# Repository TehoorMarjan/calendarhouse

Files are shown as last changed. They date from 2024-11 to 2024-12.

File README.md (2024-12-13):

# DIY Smart Advent Calendar House 🎄

> [!WARNING]  
> This project is a work in progress. While it can serve as inspiration, it is not ready for plug-and-play use and requires additional development and customization.

<div align="center">
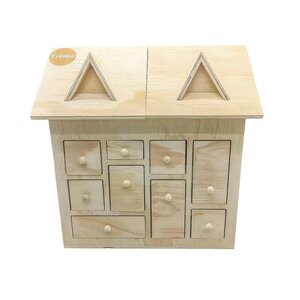
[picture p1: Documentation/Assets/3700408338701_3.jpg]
  
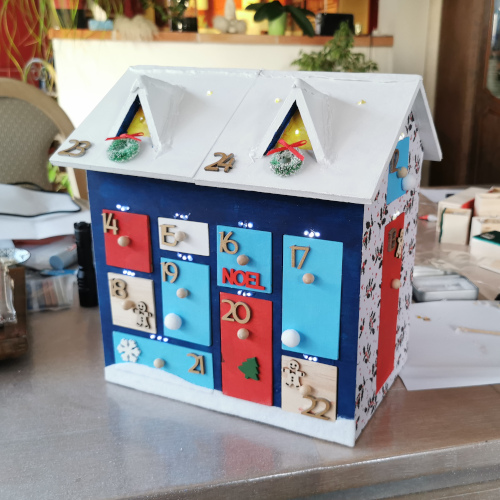
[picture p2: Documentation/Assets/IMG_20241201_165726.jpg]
  
</div>

A fun, interactive advent calendar looking like a miniature wooden house with a drawer for each day leading up to Christmas. This project combines craftsmanship with electronics to create a delightful experience for children and grown-ups!

## Project Highlights

- **Interactive LEDs**: Each day, a specific LED lights up to guide the child to the correct drawer.
- **Drawer Detection**: Detects when a drawer is opened using Hall-effect sensors and magnets.
- **Audio Playback**: Plays music, stories, or sounds depending on opened drawer, also giving feedback when wrong drawer is opened.
- **Light Show**: Features decorative light displays synchronized with sound playback. (🚧 Planned feature)

---

## Folder Structure

- **`Fritzing`**: Contains the initial schematics created with the Fritzing software.
- **`KiCAD`**: Detailed electronic schematics and PCB designs created with KiCAD.
- **`Firmware`**: A PlatformIO project featuring the ESP32 firmware (work in progress).
- **`Documentation`**: Includes relevant datasheets and schema exports.
- **`Design`**: Includes decoration ideas, paint tests, and images of the house design.

---

## Hardware Overview

### Electronics Used
1. **ESP32-WROOM**: The main microcontroller also used for USB 5V power supply.
2. **TLC5947 Module**: 24-channel PWM driver for controlling the LEDs above each drawer, From Adafruit.
3. **2x PCF8575 IO Expanders**: To read the state of the 24 drawers via Hall-effect sensors (12 IOs each, each expander can handle up to 16 IOs).
4. **MAX98357 I2C Amplifier**: For better audio output compared to the PAM8403 module. (🚧 Realised on-board, schematics to change yet.)
5. **SPI SD Card Reader**: To store music, sound effects, or stories. Could also host update files (OTA), parameters, ...
6. **Hall-effect Sensors (A3144)**: Each drawer gets a small 10x10x1 mm *neodymium* magnet *(ferrite would be too weak)* and Hall-effect sensor to detect openings. `A3144` was selected, but requires improvement due to its active-low nature ("magnet present = on" ⇒ current is drawn almost all the time). Should select a non-latching active-high sensor instead.

---

## Tools Used

- **Fritzing**: Initial circuit layout and basic design.
- **KiCAD**: Advanced schematics and PCB design for production-ready boards.
- **PlatformIO**: Development environment for writing Arduino-based firmware for the ESP32.

---

## Getting Started

### Prerequisites
- Install [PlatformIO](https://platformio.org/) to compile and upload firmware.
- Required dependencies for the ESP32 firmware can be installed using:
  ```bash
  pio pkg install
  ```

### Hardware Assembly
1. **Electronics Integration**:
   - Connect ESP32, LEDs, sensors, and audio modules as per the schematics in the `KiCAD` folder.
   - Solder the components onto the PCB designed in `KiCAD` or use a breadboard for prototyping.

2. **House Assembly**:
   - Paint and decorate the wooden house using ideas from the `Design` folder.
   - Attach the LEDs above each drawer and install Hall-effect sensors inside.

3. **Calibration**:
   - Test the sensor detection and calibrate the thresholds for drawer opening/closing.
   - Load the firmware onto the ESP32 to test the LED control and audio playback.

## Future Enhancements

- Add Wi-Fi capabilities for remote control (🚧 ongoing).
- Integrate a mobile/web app.
- Explore active-high Hall-effect sensors for smoother drawer state detection.

## License

Feel free to reuse components of this project, **subject to their respective licenses**. Please note that third-party components (such as Fritzing and KiCAD parts) may have their own licensing terms, which you should review accordingly. (⚠️ TODO: Check the licenses for each part).

### My Original Work:

Released under [CC0 1.0 Universal (Public Domain Dedication)](https://creativecommons.org/publicdomain/zero/1.0/). This means you can use *my* artwork and *my* code for any purpose without any restrictions.

In short, you are free to use, modify, and distribute both the code and artwork with very few limitations.

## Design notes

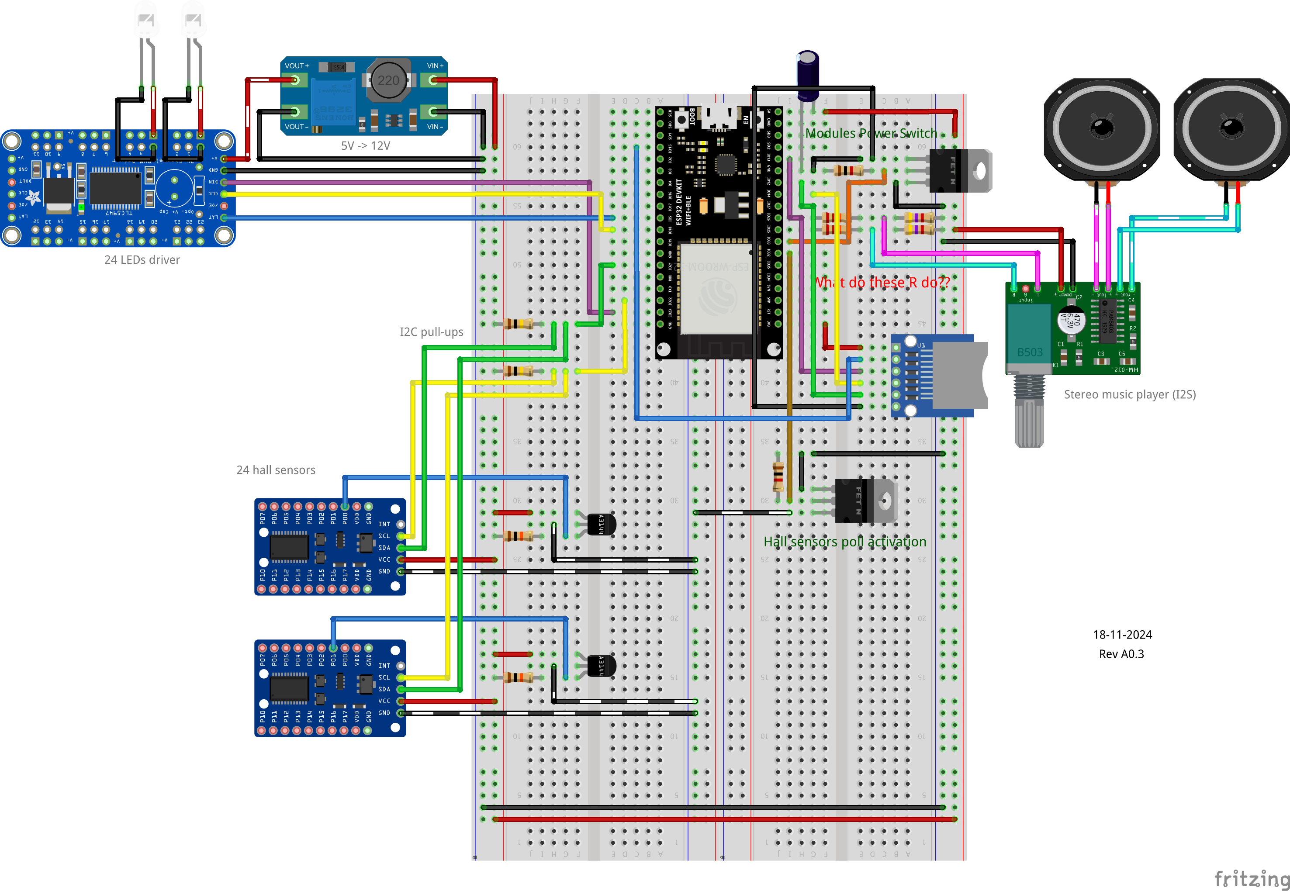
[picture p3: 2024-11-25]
Documentation/Exports/CalendarHouse_bb.png

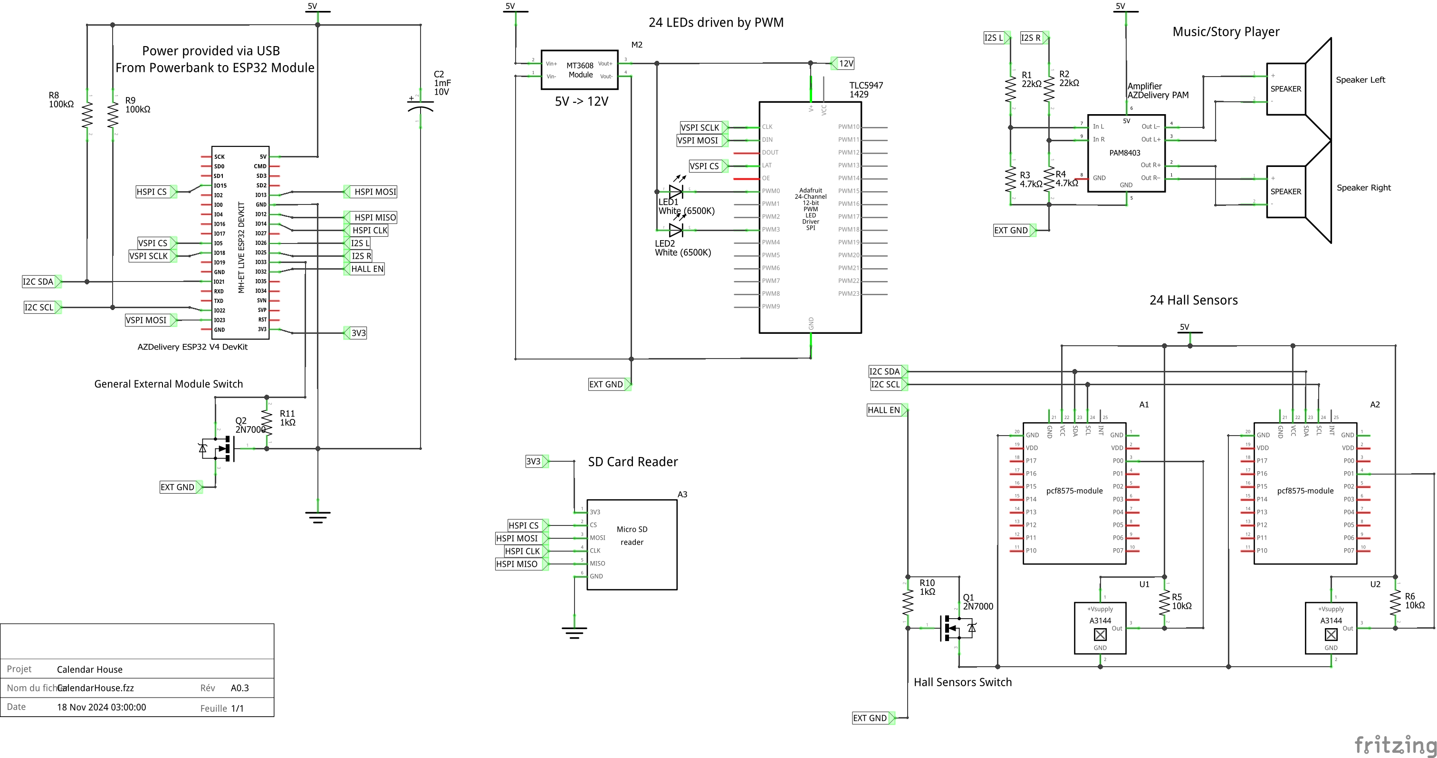
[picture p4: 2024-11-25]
Documentation/Exports/CalendarHouse_sch.png

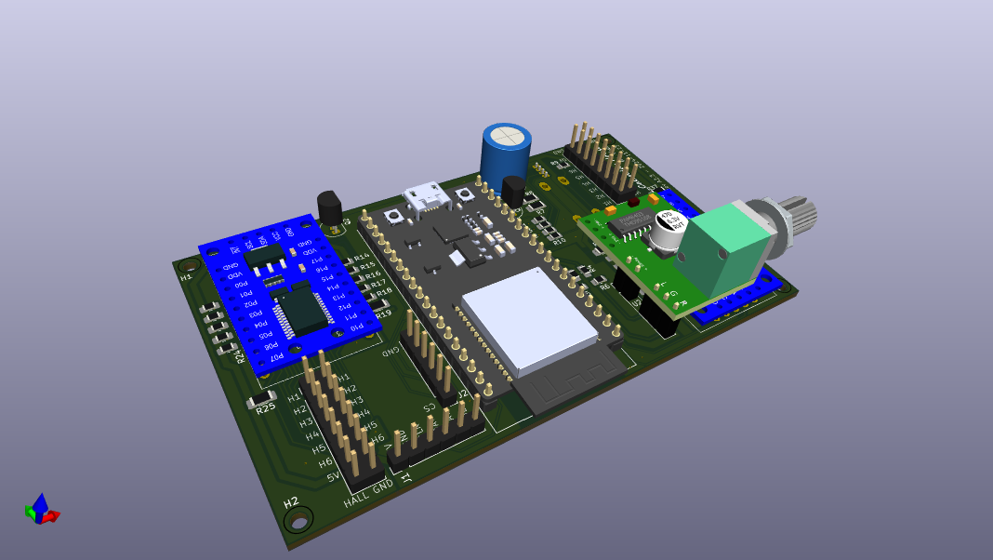
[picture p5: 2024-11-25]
Documentation/Exports/CalendarHouse3D.png

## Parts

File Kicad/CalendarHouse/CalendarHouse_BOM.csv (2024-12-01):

Reference | Value | Datasheet | Footprint | Qty | DNP | Availability
C1 | 1m | ~ | Capacitor_THT:C_Radial_D10.0mm_H12.5mm_P5.00mm | 1 |  | In Stock
R13 | 68 | ~ | Resistor_SMD:R_0805_2012Metric_Pad1.20x1.40mm_HandSolder | 1 |  | Ordered
R7,R8 | 100 | ~ | Resistor_SMD:R_1206_3216Metric_Pad1.30x1.75mm_HandSolder | 2 |  | Ordered
R11 | 100 | ~ | Resistor_SMD:R_0805_2012Metric_Pad1.20x1.40mm_HandSolder | 1 |  | Ordered
R12 | 220 | ~ | Resistor_SMD:R_0805_2012Metric_Pad1.20x1.40mm_HandSolder | 1 |  | Ordered
R1,R2,R9 | 2.2K | ~ | Resistor_SMD:R_0805_2012Metric_Pad1.20x1.40mm_HandSolder | 3 |  | Ordered
R5,R6,R10 | 4.7K | ~ | Resistor_SMD:R_0805_2012Metric_Pad1.20x1.40mm_HandSolder | 3 |  | Ordered
R14,R15,R16,R17,R18,R20,R21,R22,R23,R24,R26,R27,R28,R29,R30,R32,R33,R34,R35,R36 | 10K | ~ | Resistor_SMD:R_0805_2012Metric_Pad1.20x1.40mm_HandSolder | 20 |  | Ordered
R19,R25,R31,R37 | 10K | ~ | Resistor_SMD:R_1206_3216Metric_Pad1.30x1.75mm_HandSolder | 4 |  | Ordered
R3,R4 | 22K | ~ | Resistor_SMD:R_0805_2012Metric_Pad1.20x1.40mm_HandSolder | 2 |  | Ordered
Q1,Q2 | 2N7000 | https://www.vishay.com/docs/70226/70226.pdf | Package_TO_SOT_THT:TO-92_Inline | 2 |  | In Stock
U2 | AZPAM8403 | https://cdn.shopify.com/s/files/1/1509/1638/files/Mini-PAM8403_datasheet.pdf?v=1646835767 | Kicad:Mini PAM8403 Module OnlyInput | 1 |  | In Stock
J3,J4 | Conn_02x08_Odd_Even | ~ | Connector_PinHeader_2.54mm:PinHeader_2x08_P2.54mm_Vertical | 2 |  | Ordered
J1 | Conn_1x6_LED_MOD | ~ | Connector_PinHeader_2.54mm:PinHeader_1x06_P2.54mm_Vertical | 1 |  | Ordered
J2 | Conn_1x6_SD_CARD | ~ | Connector_PinHeader_2.54mm:PinHeader_1x06_P2.54mm_Vertical | 1 |  | Ordered
U1 | DEVKIT_V1_ESP32-WROOM-32 | https://www.espressif.com/sites/default/files/documentation/esp32_datasheet_en.pdf | Kicad:MODULE_DEVKIT_V1_ESP32-WROOM-32 | 1 |  | In Stock
D1 | LED_RKBG | https://www.farnell.com/datasheets/3497864.pdf | LED_THT:LED_D5.0mm-4_RGB | 1 |  | In Stock
SW1 | SW_Push | https://sten-eswitch-13110800-production.s3.amazonaws.com/system/asset/product_line/data_sheet/143/TL1100.pdf | Button_Switch_THT:SW_PUSH-12mm | 1 |  | In Stock
U3,U4 | ZKEESHOP_PCF8575_MOD | https://www.tinytronics.nl/shop/index.php?route=product/product/get_file&file=3903/pcf8575.pdf | Kicad:16-bit IO Expander | 2 |  | In Stock

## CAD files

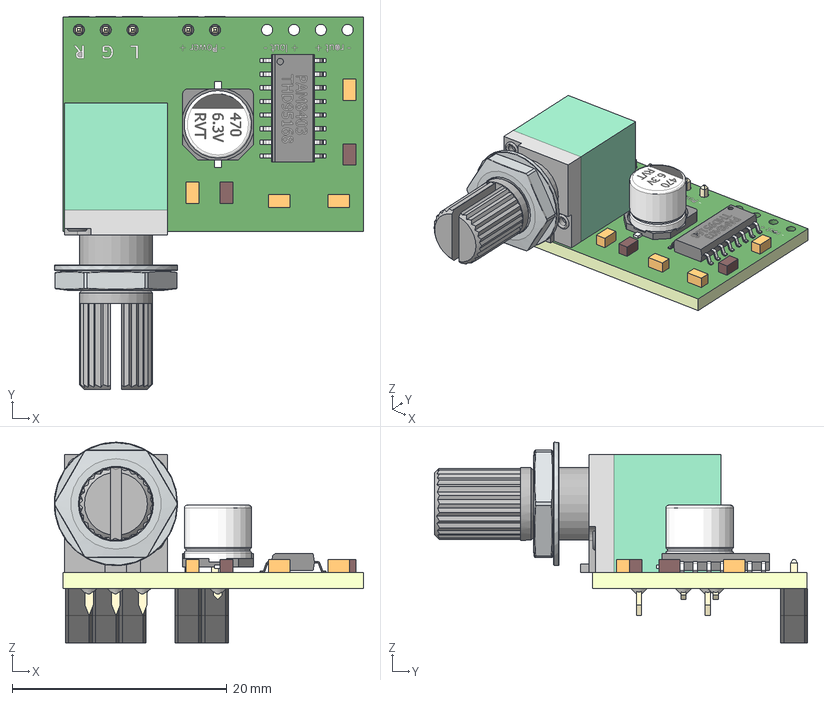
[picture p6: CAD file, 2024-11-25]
Kicad/Parts/PAM8403 5V 2 Channel USB Digital Audio with Potentionmeter Switch Modded.stp
28.8 x 34.7 x 18.7 mm
PAM8403 5V 2 Channel USB Digital Audio with Potentionmeter Switch009
PAM8403 5V 2 Channel USB Digital Audio with Potentionmeter Switch010
PAM8403 5V 2 Channel USB Digital Audio with Potentionmeter Switch011
PAM8403 5V 2 Channel USB Digital Audio with Potentionmeter Switch013 x 2
PAM8403 5V 2 Channel USB Digital Audio with Potentionmeter Switch014 x 2
PAM8403 5V 2 Channel USB Digital Audio with Potentionmeter Switch015
PAM8403 5V 2 Channel USB Digital Audio with Potentionmeter Switch016
PAM8403 5V 2 Channel USB Digital Audio with Potentionmeter Switch017
PAM8403 5V 2 Channel USB Digital Audio with Potentionmeter Switch022
PAM8403 5V 2 Channel USB Digital Audio with Potentionmeter Switch023
PAM8403 5V 2 Channel USB Digital Audio with Potentionmeter Switch033

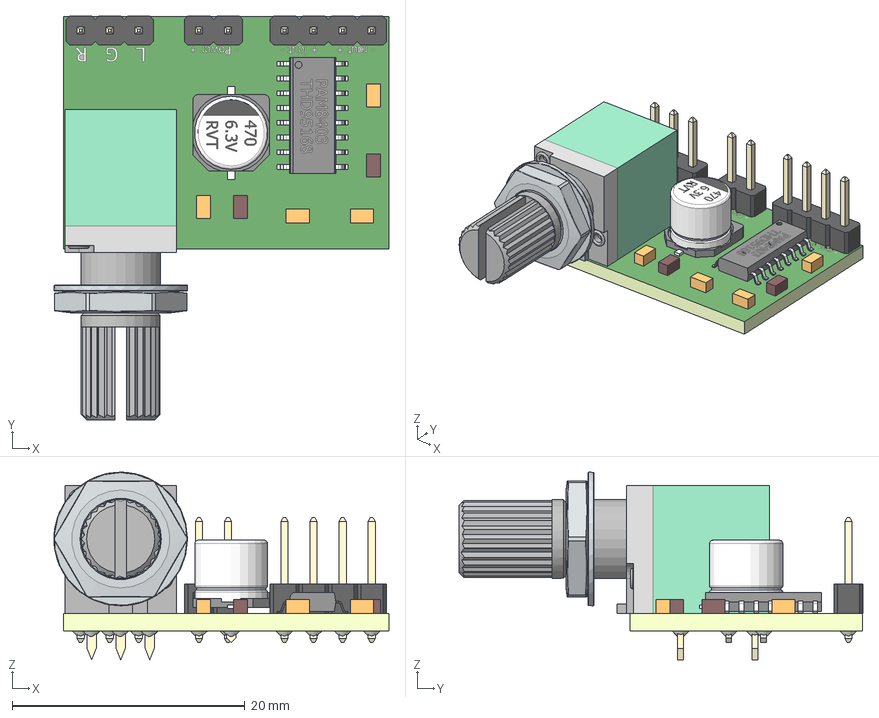
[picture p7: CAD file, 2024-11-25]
Kicad/Parts/PAM8403 5V 2 Channel USB Digital Audio with Potentionmeter Switch.stp
28.8 x 34.7 x 16.1 mm

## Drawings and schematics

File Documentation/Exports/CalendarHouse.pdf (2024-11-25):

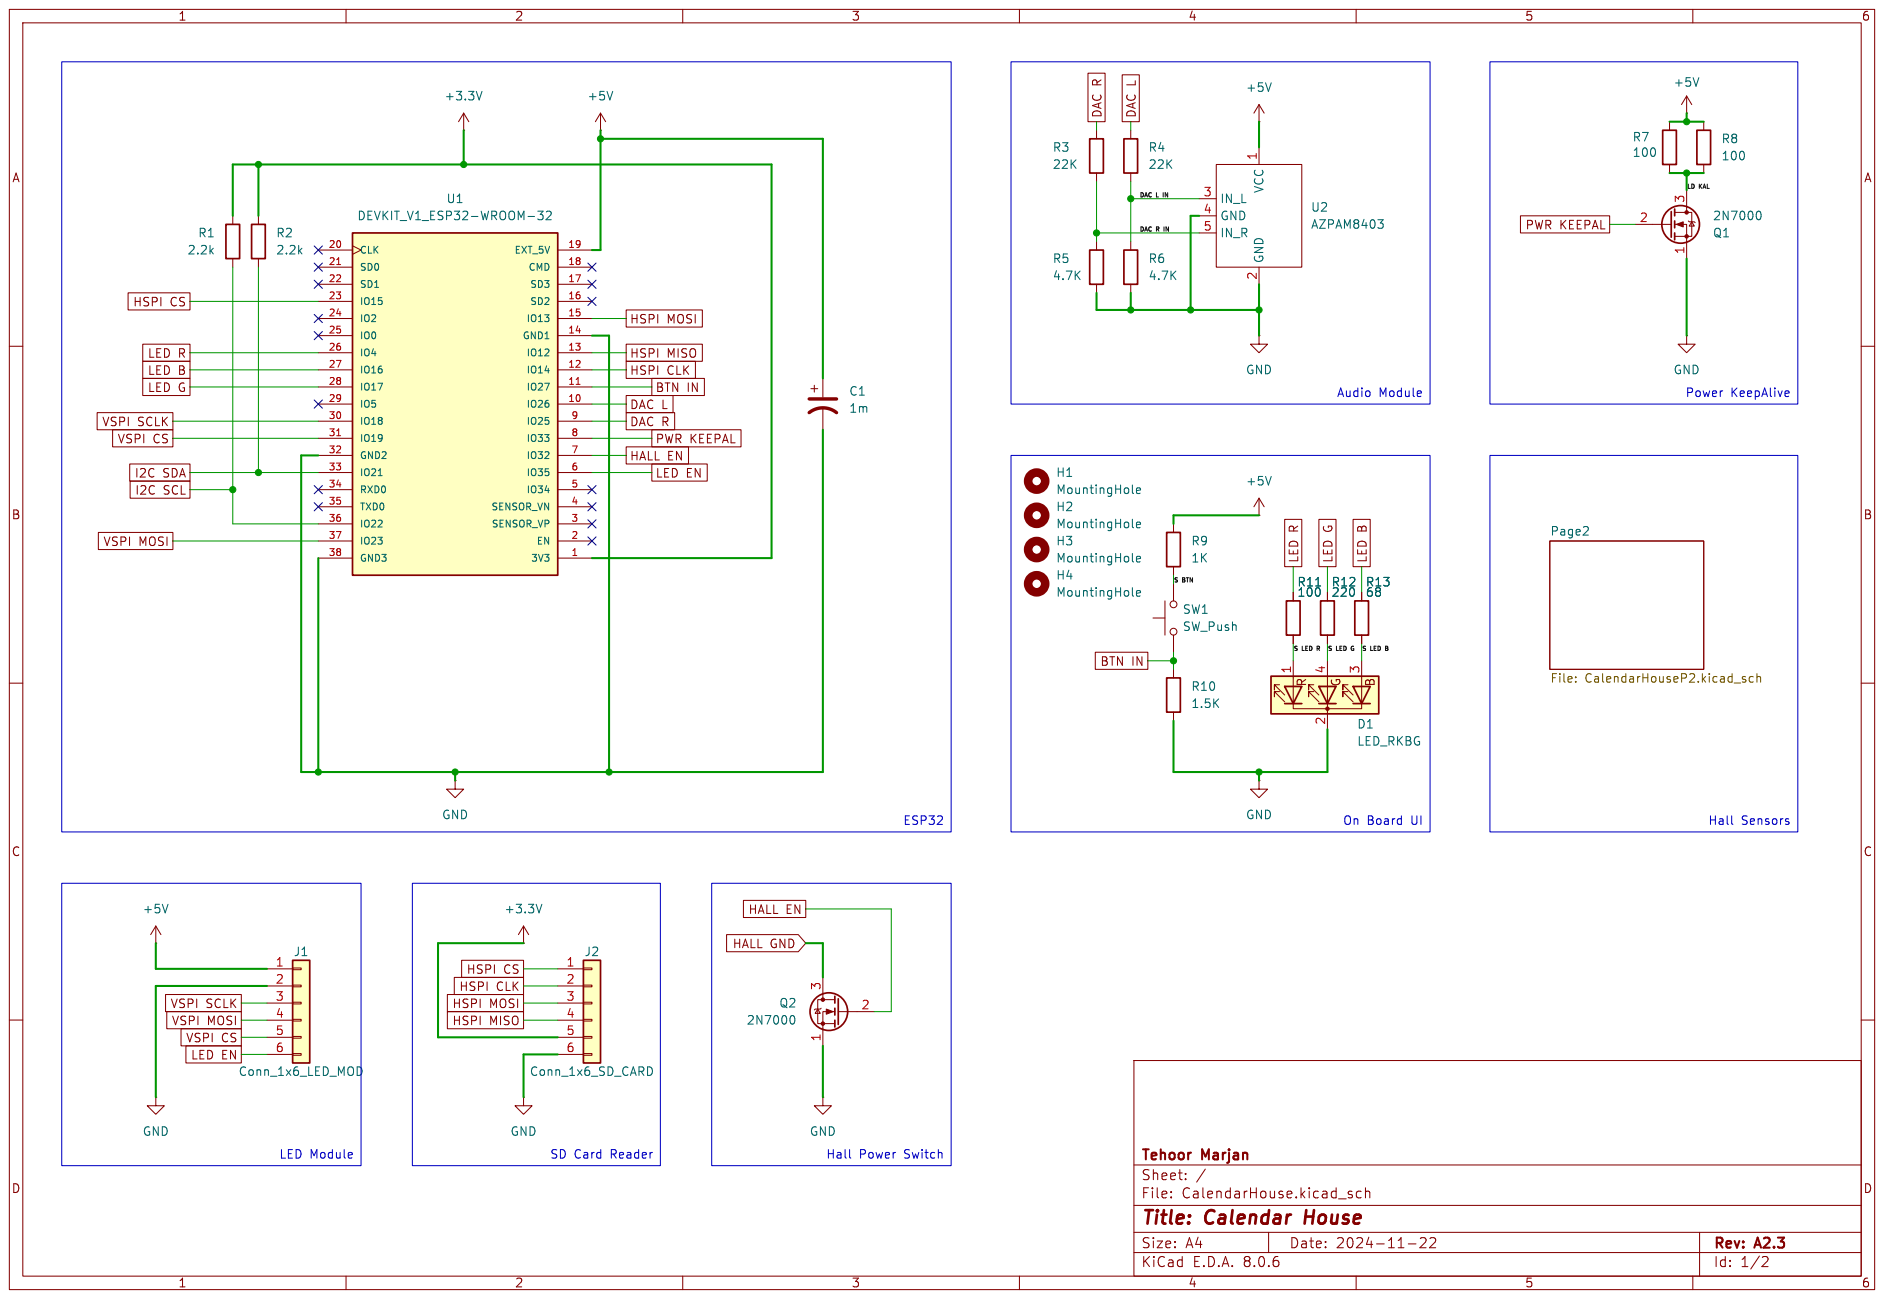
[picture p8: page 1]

LD KAL DAC L IN

PWR KEEPAL HSPI CLK HSPI MOSI
HSPI MOSI HALL EN

PWR KEEPAL HSPI MISO
HSPI CLK
BTN IN

VSPI MOSI VSPI SCLK

Id: 1/2 Title: Calendar House

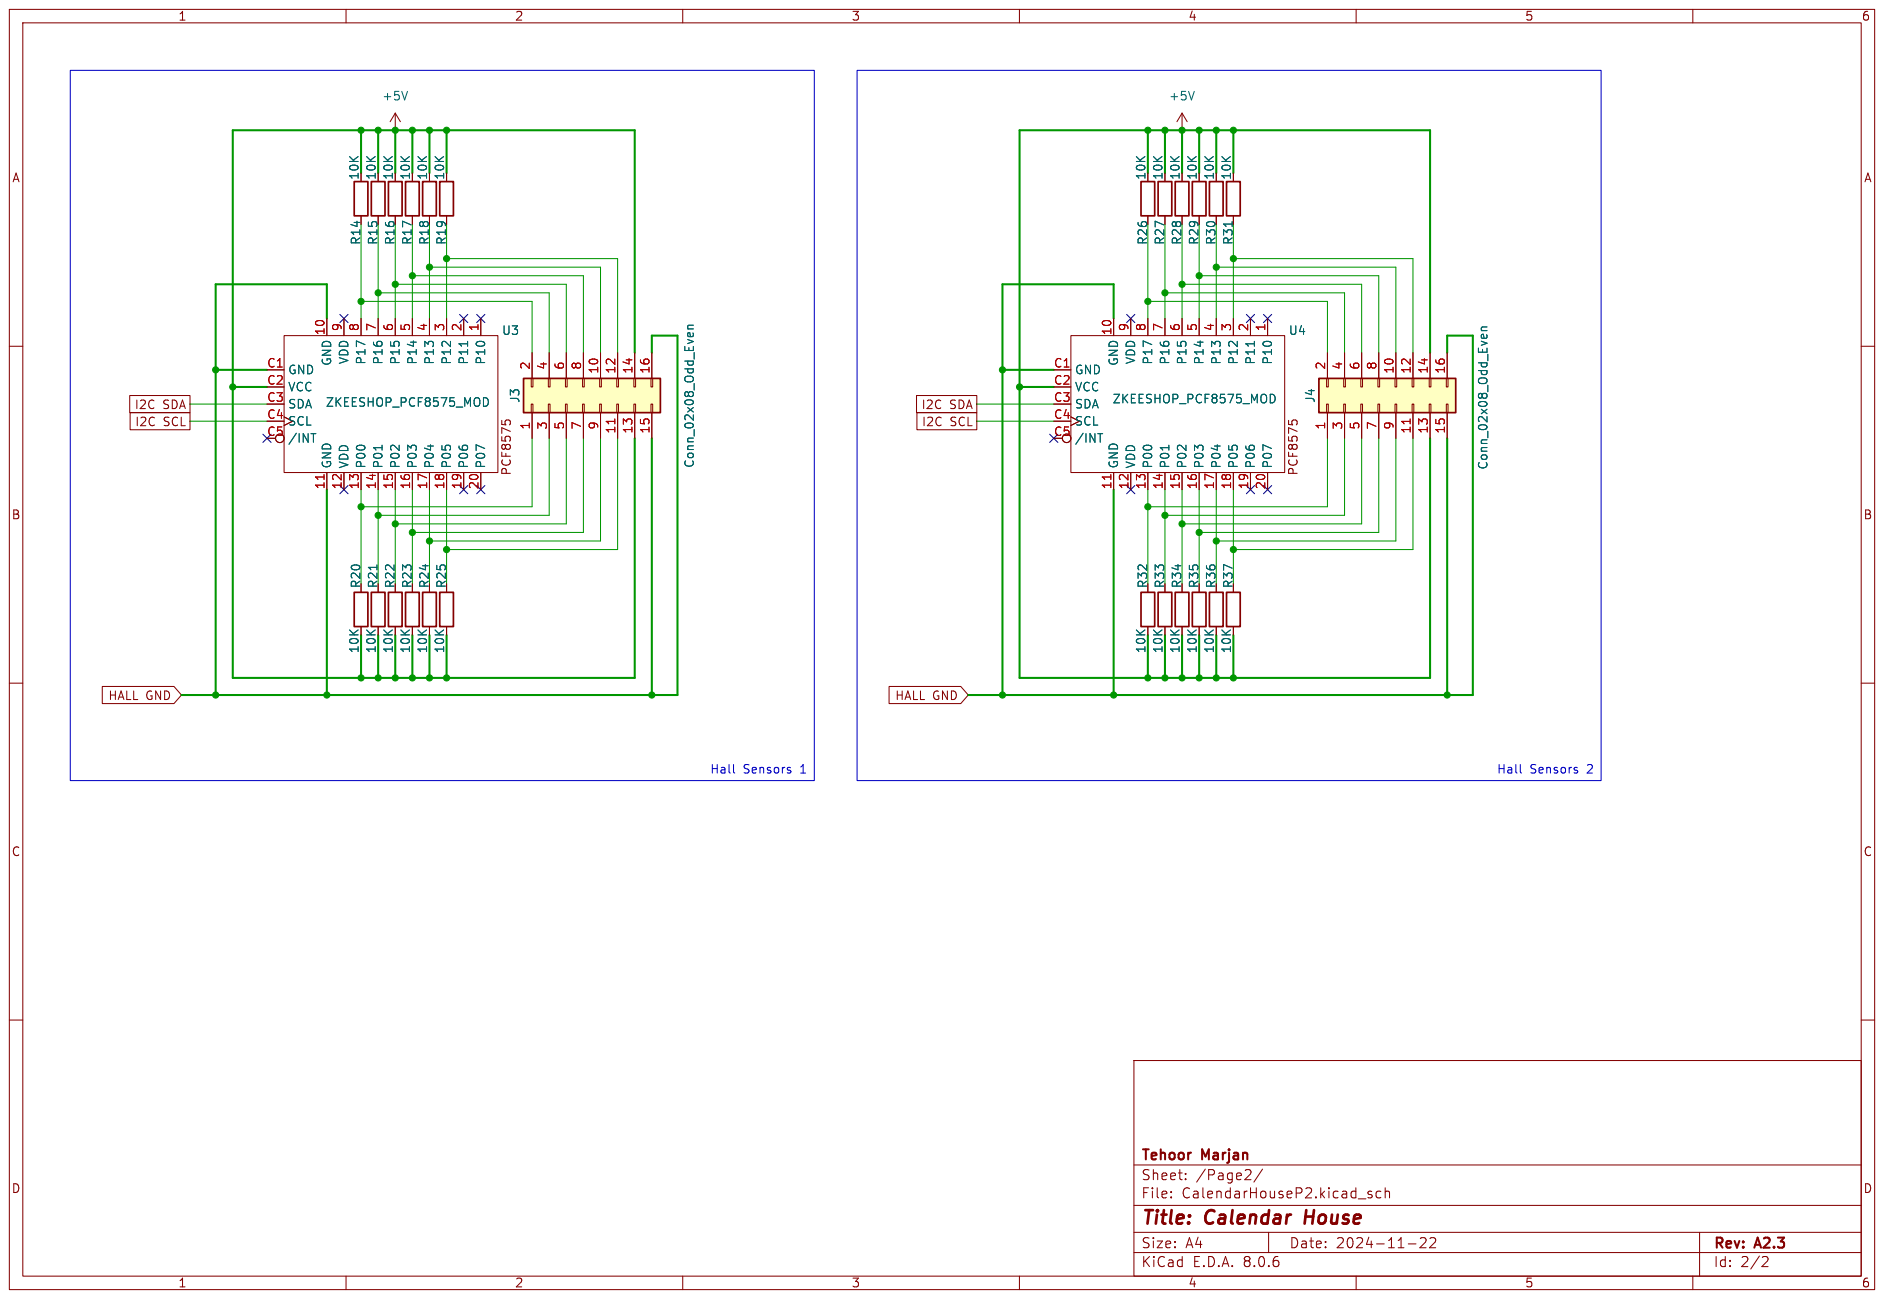
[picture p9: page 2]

9 GND C1 VCC C2 SDA C3 SCL C4

Id: 2/2 Title: Calendar House

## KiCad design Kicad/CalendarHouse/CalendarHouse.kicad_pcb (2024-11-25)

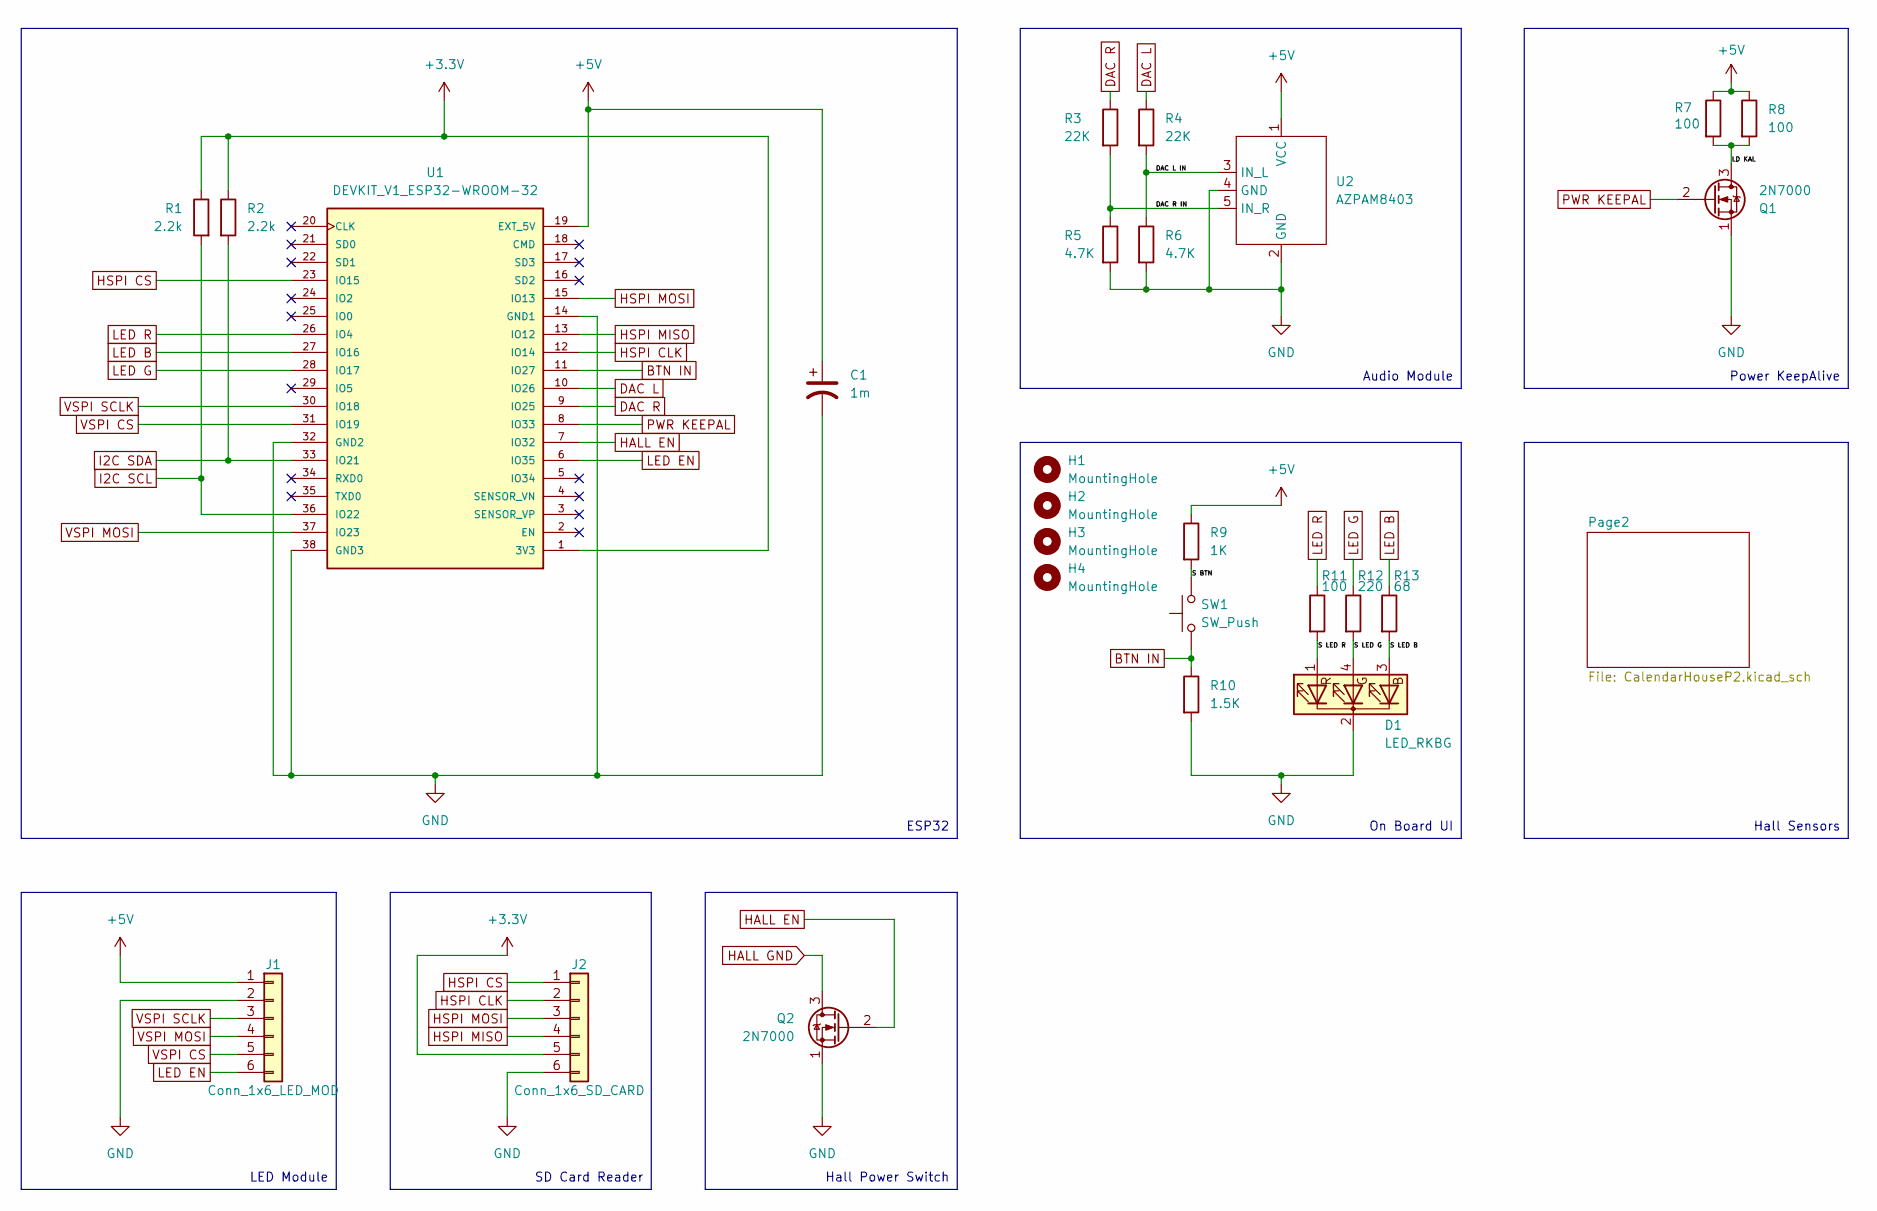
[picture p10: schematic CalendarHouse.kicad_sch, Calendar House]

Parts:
C1: 1m; C_Radial_D10.0mm_H12.5mm_P5.00mm
D1: LED_RKBG; LED_D5.0mm-4_RGB
H1, H2, H3, H4: MountingHole; MountingHole_2.2mm_M2_DIN965
J1: Conn_1x6_LED_MOD; PinHeader_1x06_P2.54mm_Vertical
J2: Conn_1x6_SD_CARD; PinHeader_1x06_P2.54mm_Vertical
Q1, Q2: 2N7000; TO-92_Inline
R1, R2: 2.2k; R_0805_2012Metric_Pad1.20x1.40mm_HandSolder
R3, R4: 22K; R_0805_2012Metric_Pad1.20x1.40mm_HandSolder
R5, R6: 4.7K; R_0805_2012Metric_Pad1.20x1.40mm_HandSolder
R7, R8: 100; R_1206_3216Metric_Pad1.30x1.75mm_HandSolder
R9: 1K; R_0805_2012Metric_Pad1.20x1.40mm_HandSolder
R10: 1.5K; R_0805_2012Metric_Pad1.20x1.40mm_HandSolder
R11: 100; R_0805_2012Metric_Pad1.20x1.40mm_HandSolder
R12: 220; R_0805_2012Metric_Pad1.20x1.40mm_HandSolder
R13: 68; R_0805_2012Metric_Pad1.20x1.40mm_HandSolder
SW1: SW_Push; SW_PUSH-12mm; MPN TL1100D
U1: DEVKIT_V1_ESP32-WROOM-32; MODULE_DEVKIT_V1_ESP32-WROOM-32; PARTREV N/A
U2: AZPAM8403; Mini PAM8403 Module OnlyInput

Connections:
+3.3V: J2.5, R1.1, R2.1, U1.1 (3V3)
+5V: C1.1, J1.1, R7.1, R8.1, R9.1, U1.19 (EXT_5V), U2.1 (VCC); also elsewhere on the board
/DAC L IN: R4.2, R6.1, U2.3 (IN_L)
/DAC R IN: R3.2, R5.1, U2.5 (IN_R)
/LD KAL: Q1.3 (D), R7.2, R8.2
/S BTN: R9.2, SW1.2
/S LED B: D1.3 (BA), R13.2
/S LED G: D1.4 (GA), R12.2
/S LED R: D1.1 (RA), R11.2
BTN IN: R10.1, SW1.1, U1.11 (IO27)
DAC L: R4.1, U1.10 (IO26)
DAC R: R3.1, U1.9 (IO25)
GND: C1.2, D1.2 (K), J1.2, J2.6, Q1.1 (S), Q2.1 (S), R5.2, R6.2, R10.2, U1.14 (GND1), U1.32 (GND2), U1.38 (GND3), U2.2 (GND), U2.4 (GND)
HALL EN: Q2.2 (G), U1.7 (IO32)
HALL GND: Q2.3 (D); also elsewhere on the board
HSPI CLK: J2.2, U1.12 (IO14)
HSPI CS: J2.1, U1.23 (IO15)
HSPI MISO: J2.4, U1.13 (IO12)
HSPI MOSI: J2.3, U1.15 (IO13)
I2C SCL: R1.2, U1.36 (IO22); also elsewhere on the board
I2C SDA: R2.2, U1.33 (IO21); also elsewhere on the board
LED B: R13.1, U1.27 (IO16)
LED EN: J1.6, U1.6 (IO35)
LED G: R12.1, U1.28 (IO17)
LED R: R11.1, U1.26 (IO4)
PWR KEEPAL: Q1.2 (G), U1.8 (IO33)
VSPI CS: J1.5, U1.31 (IO19)
VSPI MOSI: J1.4, U1.37 (IO23)
VSPI SCLK: J1.3, U1.30 (IO18)

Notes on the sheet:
Power KeepAlive
Audio Module
LED Module
ESP32
Hall Sensors
Hall Power Switch
On Board UI
SD Card Reader

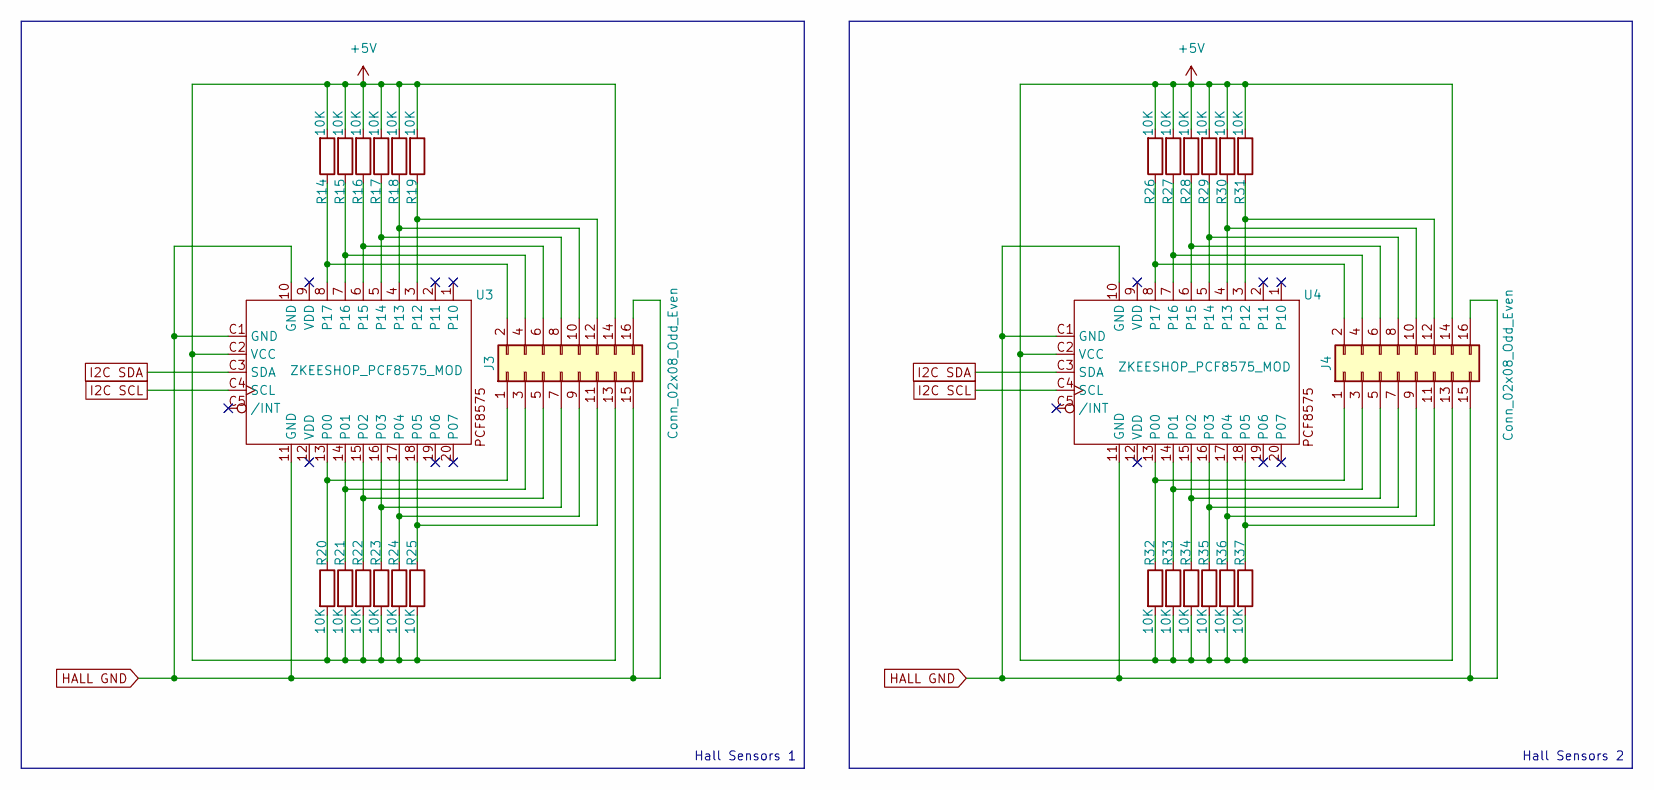
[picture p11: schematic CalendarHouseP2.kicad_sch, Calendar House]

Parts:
J3, J4: Conn_02x08_Odd_Even; PinHeader_2x08_P2.54mm_Vertical
R14, R15, R16, R17, R18, R20, R21, R22, R23, R24, R26, R27, R28, R29, R30, R32, R33, R34, R35, R36: 10K; R_0805_2012Metric_Pad1.20x1.40mm_HandSolder
R19, R25, R31, R37: 10K; R_1206_3216Metric_Pad1.30x1.75mm_HandSolder
U3, U4: ZKEESHOP_PCF8575_MOD; 16-bit IO Expander

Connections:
+5V: J3.13, J3.14, J4.13, J4.14, R14.2, R15.2, R16.2, R17.2, R18.2, R19.2, R20.2, R21.2, R22.2, R23.2, R24.2, R25.2, R26.2, R27.2, R28.2, R29.2, R30.2, R31.2, R32.2, R33.2, R34.2, R35.2, R36.2, R37.2, U3.C2 (VCC), U4.C2 (VCC); also elsewhere on the board
HALL GND: J3.15, J3.16, J4.15, J4.16, U3.10 (GND), U3.11 (GND), U3.C1 (GND), U4.10 (GND), U4.11 (GND), U4.C1 (GND); also elsewhere on the board
I2C SCL: U3.C4 (SCL), U4.C4 (SCL); also elsewhere on the board
I2C SDA: U3.C3 (SDA), U4.C3 (SDA); also elsewhere on the board
unnamed: J3.1, R20.1, U3.13 (P00)
unnamed: J3.2, R14.1, U3.8 (P17)
unnamed: J3.3, R21.1, U3.14 (P01)
unnamed: J3.4, R15.1, U3.7 (P16)
unnamed: J3.5, R22.1, U3.15 (P02)
unnamed: J3.6, R16.1, U3.6 (P15)
unnamed: J3.7, R23.1, U3.16 (P03)
unnamed: J3.8, R17.1, U3.5 (P14)
unnamed: J3.9, R24.1, U3.17 (P04)
unnamed: J3.10, R18.1, U3.4 (P13)
unnamed: J3.11, R25.1, U3.18 (P05)
unnamed: J3.12, R19.1, U3.3 (P12)
unnamed: J4.1, R32.1, U4.13 (P00)
unnamed: J4.2, R26.1, U4.8 (P17)
unnamed: J4.3, R33.1, U4.14 (P01)
unnamed: J4.4, R27.1, U4.7 (P16)
unnamed: J4.5, R34.1, U4.15 (P02)
unnamed: J4.6, R28.1, U4.6 (P15)
unnamed: J4.7, R35.1, U4.16 (P03)
unnamed: J4.8, R29.1, U4.5 (P14)
unnamed: J4.9, R36.1, U4.17 (P04)
unnamed: J4.10, R30.1, U4.4 (P13)
unnamed: J4.11, R37.1, U4.18 (P05)
unnamed: J4.12, R31.1, U4.3 (P12)

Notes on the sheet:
Hall Sensors 1
Hall Sensors 2

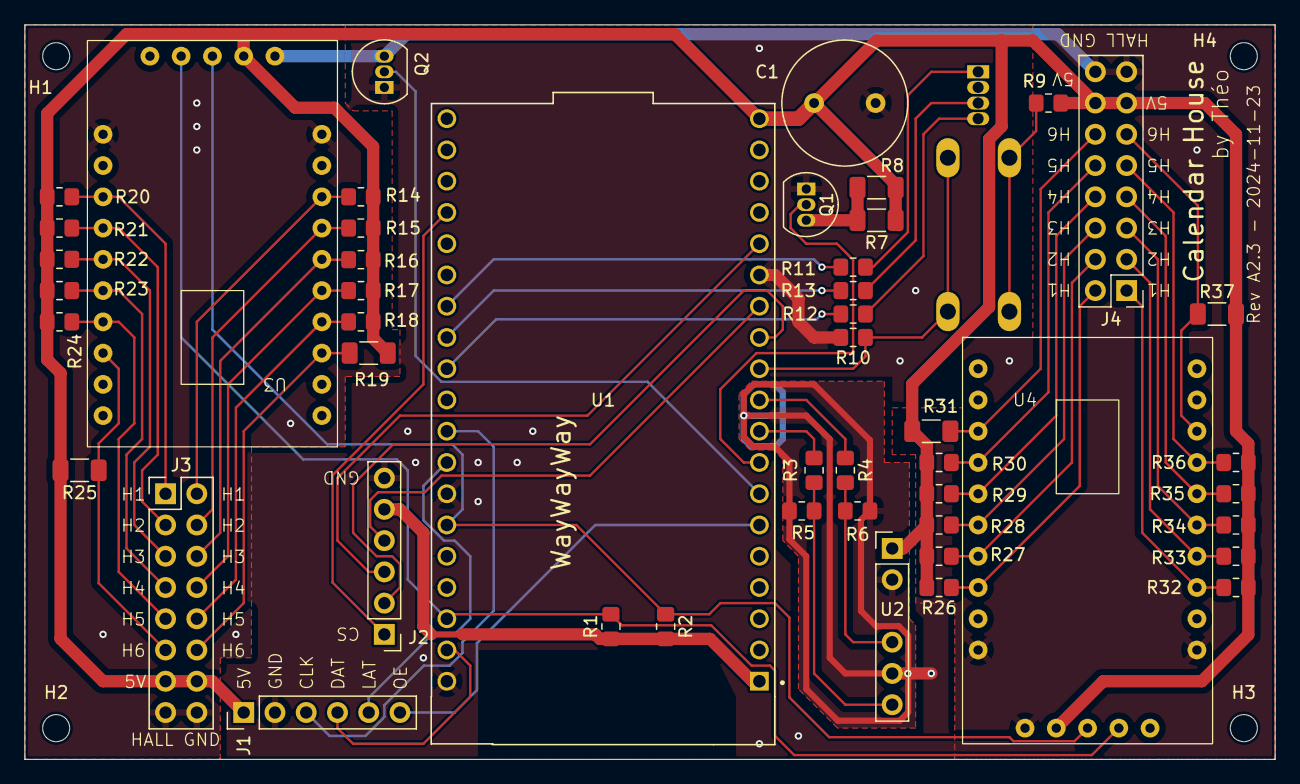
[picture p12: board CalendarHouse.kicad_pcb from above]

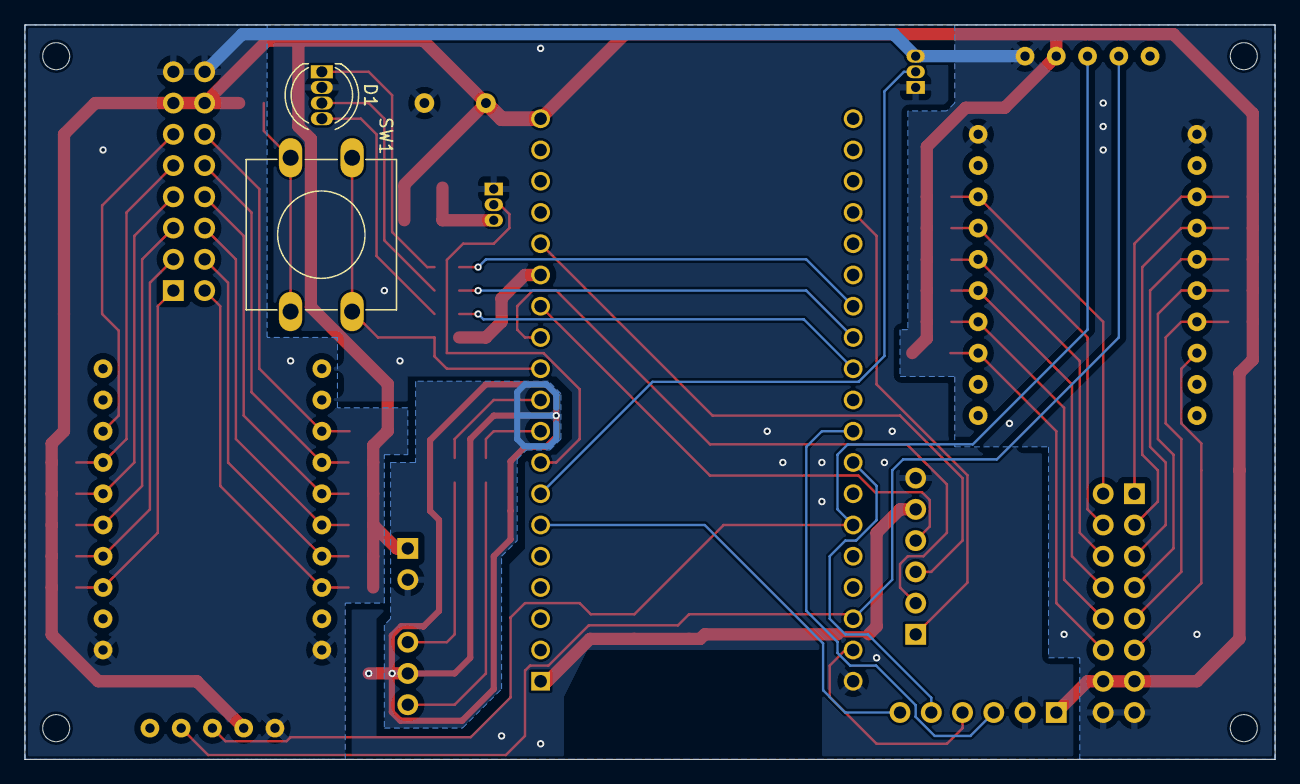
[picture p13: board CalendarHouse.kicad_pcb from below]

Board: 2 copper layers, 101.6 x 59.7 mm, 54 parts (2 on the bottom side), 53 nets.

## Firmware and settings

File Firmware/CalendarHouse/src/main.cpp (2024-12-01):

#include "board.h"
#include "sd_card.h"
#include "leds.h"
#include "audio_task.h"
#include <WiFiManager.h>
#include "time.h"

SDCardManager sdCardManager;
LedController ledController;
AudioTask audioTask(sdCardManager);
WiFiManager wifiManager;

const char* ntpServer = "pool.ntp.org";
const long  gmtOffset_sec = 0;
const int   daylightOffset_sec = 3600;

void timeCheckTask( void * pvParameters );
void ledTask( void * pvParameters );

void setup() {
  
  Serial.begin(115200);
  sdCardManager.begin();
  ledController.begin();

  while (!Serial) {
    delay(10);
  }

  if (!sdCardManager.isCardPresent()) {
    Serial.println("No SD card attached");
  }
  else {
    Serial.printf("SD Card Size: %lluMB\n", sdCardManager.cardSizeMB());
    Serial.printf("Total space: %lluMB\n", sdCardManager.totalSpaceMB());
    Serial.printf("Used space: %lluMB\n", sdCardManager.usedSpaceMB());
  }

  wifiManager.setHostname("calendarhouse");
  wifiManager.setWiFiAutoReconnect(true);
  wifiManager.autoConnect("CalendarHouse");

  Serial.println("Connected to WiFi");

  configTime(gmtOffset_sec, daylightOffset_sec, ntpServer);
  xTaskCreatePinnedToCore(
    ledTask,                /* Task function. */
    "ledTask",              /* String with name of task. */
    10000,                  /* Stack size in words. */
    NULL,                   /* Parameter to pass to the task. */
    1,                      /* Task priority. */
    NULL,                   /* Task handle. */
    1);                     /* Core where the task should run. */

  xTaskCreatePinnedToCore(
    timeCheckTask,          /* Task function. */
    "timeCheckTask",        /* String with name of task. */
    10000,                  /* Stack size in words. */
    NULL,                   /* Parameter to pass to the task. */
    1,                      /* Task priority. */
    NULL,                   /* Task handle. */
    1);                     /* Core where the task should run. */
}

void timeCheckTask( void * pvParameters ){
  struct tm timeinfo;
  for(;;){
    if(!getLocalTime(&timeinfo)){
      Serial.println("Failed to obtain time");
    }
    else {
      ledController.setActiveDay(timeinfo.tm_wday);
    }
    vTaskDelay(1000 / portTICK_PERIOD_MS);
  }
}

void ledTask( void * pvParameters ){
  for(;;){
    ledController.loop();
    vTaskDelay(10 / portTICK_PERIOD_MS);
  }
}

void loop() {
  audioTask.loop();
}

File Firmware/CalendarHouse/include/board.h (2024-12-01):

/**
 * @file board.h
 * @brief This file lists all defines related to port assignment of functions specific to this board
 */

#ifndef BOARD_H
#define BOARD_H

#include <SPI.h>

// SD Card
#define SD_SPI              (HSPI)

#define SD_PIN_CS           (15)
#define SD_PIN_MISO         (12)
#define SD_PIN_MOSI         (13)
#define SD_PIN_CLK          (14)

// PWM LED Controller
#define CAL_LED_SPI         (VSPI)
#define CAL_LED_FREQ        (30000000) // Use 15000000 if chaining modules
#define CAL_LED_NBCHAIN     (1)

#define CAL_LED_PIN_CS      (19)
#define CAL_LED_PIN_MOSI    (23)
#define CAL_LED_PIN_CLK     (18)
#define CAL_LED_PIN_EN      (-1)

// Audio
#define I2S_PIN_DOUT        (25)
#define I2S_PIN_BCLK        (27)
#define I2S_PIN_LRC         (26)

#endif

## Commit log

2024-11-25 First Commit
    - Archived Fritzing project, replaced by Kicad
    - Kicad project sent to production at PCBWay
    - Includes color research of houses
    [CalendarHouse.fzz, CalendarHouse.kicad_pcb, CalendarHouse.kicad_sch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]
2024-11-25 PlatformIO Init and SD Card
    - Init PlatformIO for Firmware
    - Had to burn eFuses due to GPIO12 missuse
    - Proof Of Concept for SD Card Reader
    [main.cpp]
2024-11-26 PoC LED PWM
    - Using Adafruit lib bitbanger
    - Cleaned SD Card
    - GPIO35 is not suitable for LED_EN
    [CalendarHouse.kicad_sch]
2024-11-27 LED Driver
    - Own LED driver
2024-11-27 Add Audio Controller
    - Audio Task
    - Currently, poor sound output
    - Should move to own task
2024-12-01 Update Schematics due to missing resistor value
    - Corrected Design
    - New resistors for button due to 1.5k missing in my set
    [CalendarHouse.kicad_sch, CalendarHouse_BOM.csv]
2024-12-01 Added Mono Audio
    - Using ESP32-audioI2S
    - MAX98357a
    - Works great
2024-12-01 Add network control
    - WifiManager
    - Hostname
    [partitions.csv]
2024-12-01 Leds
    - Doesn't work yet
    [leds.cpp, main.cpp]
